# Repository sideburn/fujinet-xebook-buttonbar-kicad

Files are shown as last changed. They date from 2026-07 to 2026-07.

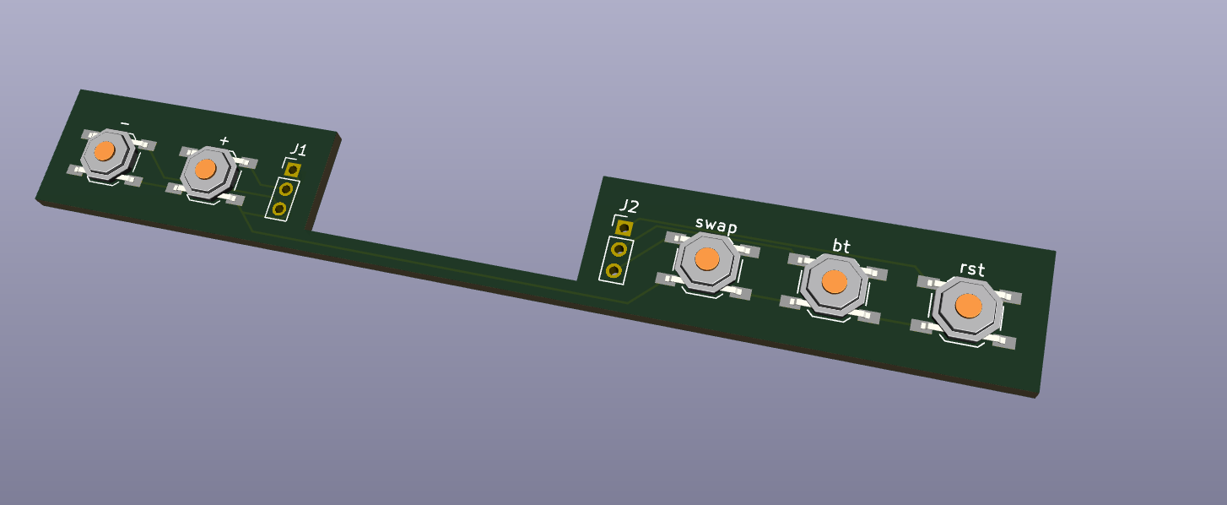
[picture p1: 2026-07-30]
Graphics/Screenshot 2025-03-12 at 2.50.07 AM.png

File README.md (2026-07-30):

# XEBook Button Bar

A panel-mount board carrying five tactile buttons for the
[FN32ROV-XEBook-KiCad](../FN32ROV-XEBook-KiCad) main board, which mounts the FujiNet
FN32ROV WiFi/SIO adapter permanently inside an XEBook laptop build.

On the main board, the buttons were moved off-PCB onto cable pigtails so they can be
panel-mounted separately (see that project's `CLAUDE.md`, "External button bar interface
(J_BTN1)"). This board is that panel-mounted button bar.

## What's on it

- SW1 ("-") / SW2 ("+") — volume down / volume up, wired to **J1**.
- SW3 ("swap") / SW4 ("bt") / SW6 ("rst") — the three FujiNet control buttons (swap
  device, Bluetooth, reset), wired to **J2**.
- All five are low-profile SMD tactile switches (E-Switch TL3342), active-low (each pulls
  its signal to GND when pressed).
- **J1** — 3-pin `PinHeader_1x03_P2.00mm_Vertical`, through-hole. Pin 1 = GND, pin 2 =
  volume down, pin 3 = volume up.
- **J2** — 4-pin `PinHeader_1x04_P2.00mm_Vertical`, through-hole. Pin 1 = GND, pin 2 =
  swap, pin 3 = Bluetooth, pin 4 = reset — matches J_BTN1 on the main board pin-for-pin.
  Cable wires are soldered directly to both connectors' pins rather than using a mating
  connector.

## Revision note: J2 upgraded from 3 pins to 4

The original J2 carried only the three FujiNet button signals with no dedicated ground
pin — those buttons' return path only worked because it shared a ground reference with
J1 through that connector's cable. J2 is now a proper 4-pin header with its own GND pin,
matching the main board's J_BTN1 connector so the two boards' cabling maps 1:1. See this
repo's `CLAUDE.md` for the technical details of the fix.

**This fix has not yet been re-fabricated.** The schematic and PCB footprint/net changes
are verified (ERC and DRC clean, no shorts), but the copper routing from J2's new pin
layout out to the existing traces needs to be finished by hand in the KiCad GUI before
ordering the next batch of boards.

## Status

Previously fabricated with the 3-pin J2 (see `production/`). The 4-pin J2 fix described
above is designed and verified but not yet routed or re-fabricated.

## Tooling

Built with KiCad 9. `kicad-cli sch erc` / `kicad-cli pcb drc --schematic-parity` are used
to verify the design.

## License

[CERN Open Hardware Licence Version 2 - Strongly Reciprocal](LICENSE)
(CERN-OHL-S-2.0), matching the main board.

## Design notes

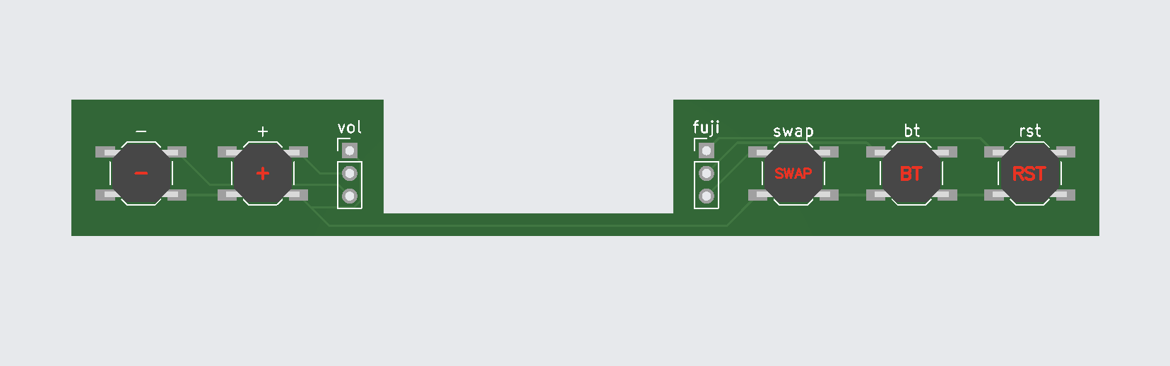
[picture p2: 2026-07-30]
Graphics/Screenshot 2025-03-12 at 2.35.47 AM.png

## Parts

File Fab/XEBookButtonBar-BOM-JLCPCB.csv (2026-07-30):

Designator | Value | Footprint | Qty | LCSC
VolDWN1,VolUP1,swap1,bt1,rst1 | SW_Push | Button_Switch_SMD:SW_SPST_TL3342 | 5

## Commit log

2026-07-30 Add XEBookButtonBar KiCad repo; fix J2 to a proper 4-pin GND connector
    J2 (the FujiNet swap/BT/reset button connector) previously carried only
    the 3 button signals with no dedicated ground pin, relying on J1's
    cable to supply GND. Upgraded J2 to a 4-pin PinHeader_1x04_P2.00mm
    header (pin 1 = GND, pins 2-4 = swap/BT/reset) so it mates 1:1 with
    J_BTN1 on the FN32ROV-XEBook main board, matching the pattern used by
    the LED and SD daughter boards in this family.
    Button-to-pin identity was confirmed against the PCB's silkscreen
    labels (swap/bt/rst), not assumed from schematic pin order, since the
    two didn't match. ERC and DRC (schematic-parity, no shorts) verified
    clean; copper routing for the ne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
    [XEBookButtonBar.kicad_pcb, XEBookButtonBar.kicad_sch]
2026-07-30 Route J2's 4th pin and add JLCPCB fab package
    Manual copper routing for J2's GND pin and the three re-numbered signal
    pads is complete. Verified with kicad-cli pcb drc (full + schematic
    parity): 0 unconnected pads, 0 shorts, only the two pre-existing
    cosmetic lib_footprint_mismatch warnings.
    Added Fab/ with gerbers, drill files (PTH/NPTH + maps), gerber job
    file, a bundled Fab.zip for JLCPCB's bare-PCB upload, and JLCPCB-format
    BOM/CPL covering the 5 SMD switches (J1/J2 are DNP -- cable wires are
    soldered directly to those through-hole pins, no header part is
    populated). The BOM's LCSC column is intentionally blank: no part
    number for the TL3342 switch was ever recorded in this project.
    Co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
    [XEBookButtonBar-BOM-JLCPCB.csv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]
2026-07-30 Sync schematic ref designators to PCB labels; regenerate fab package
    Renamed schematic reference designators to match the PCB's functional
    silkscreen labels (J1->vol, J2->fuji, SW3->swap, SW4->bt, SW6->rst),
    and renamed SW1/SW2 from the DSN/JLC-hostile "-"/"+" to VolDWN/VolUP
    in both schematic and PCB, so `-`/`+` no longer appear anywhere as a
    literal reference designator (that character choice was silently
    dropping ratsnest entries in Specctra DSN export/Freerouting and
    likely breaking JLCPCB's BOM parser, since both treat bare +/- as
    reserved tokens).
    After the user ran Update PCB from Schematic and finished routing,
    verified clean: ERC (only the pre-existing unrelated #PWR01 warning),
    an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
    [XEBookButtonBar-BOM-JLCPCB.csv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]
2026-08-02 Add B.SilkS logo artwork and regenerate the fab package
    Imports the XEBook button bar logo to B.SilkS as 68 gr_poly outlines, with the
    source artwork added under Graphics/ (.ai and .svg). The two board screenshots
    move from images/ to Graphics/ so all artwork lives in one place; images/ is now
    gone.
    Purely additive on silkscreen -- 7 footprint positions byte-identical, 51 track
    segments and 1 via identical, outline 90.550 x 12.050mm unchanged, 0 unconnected.
    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
    [XEBookButtonBar-B_Cu.gbl, XEBookButtonBar-B_Mask.gbs, XEBookButtonBar-B_Paste.gbp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]
